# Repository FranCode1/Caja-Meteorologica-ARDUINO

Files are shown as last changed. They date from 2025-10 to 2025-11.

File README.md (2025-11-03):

# 🌱 Sistema de Monitoreo Ambiental con Arduino

Este proyecto utiliza un Arduino para monitorear variables ambientales como temperatura, humedad, luminosidad, calidad del aire y humedad del suelo. 
Los datos se registran en una tarjeta SD y pueden visualizarse por consola o pantalla LCD/OLED. 
El sistema está pensado para aplicaciones agrícolas, invernaderos o estaciones meteorológicas caseras.

## ✨ Características

- ⏰ RTC DS3231 — Reloj en tiempo real
- 🌡️ MLX90614(GY-906) — Sensor de temperatura infrarrojo
- 💨 MQ-135 — Sensor de calidad del aire
- 🌞 BH1750 — Sensor de luminosidad
- 💧 DS18B20 — Sensor de Temperatura del Agua
- 🌱 Capacitive Soil Moisture v2 — Humedad del suelo
- 💾 Módulo SD — Registro de datos
- ⚡ Comunicación I2C y monitoreo por Serial
- BMP280 —
- Pantalla LCD 20x4 con interfaz i2c —
- Joystick y botones —
- TCA9548A I2C Multiplexer —
- Transformador 5v 2A —
- Baterias 3AA x3 —
- Módulo de Conmutación Automática con Condensador — 

## 🗂️ Estructura del Proyecto

    ├── src/
    │   ├── main.ino
    │   ├── DS3231.h
    │   ├── GY906.h
    │   ├── MQ135.h
    │   ├── BH1750.h
    │   ├── CSMSV2.h
    │   └── SDCard.h
    ├── README.md
    └── /docs
        └── esquema_circuito.png

Cada sensor tiene su propio archivo `.h` modularizado, con funciones:
- `iniciarX()` → Inicializa el sensor
- `leerX()` → Lee los valores y los guarda en variables globales

## ⚙️ Requisitos

- Arduino UNO / Mega / Nano
- Librerías:
  - `Wire.h`
  - `RTClib.h`
  - `Adafruit_MLX90614.h`
  - `BH1750.h`
  - `SD.h`
- Fuente de 5V estable

## 🔌 Conexiones

| Componente | Tipo  | Pin Arduino |
|---|---|---|
| DS3231 (RTC) | I2C | SDA / SCL |
| GY-906 (Temp IR) | I2C | SDA / SCL |
| BH1750 (Luz) | I2C | SDA / SCL |
| MQ-135 (Gas) | Analógico | A1 |
| Sensor Tierra | Analógico | A0 |
| SD Card Module | SPI | CS, MOSI, MISO, SCK |

## Diagrama del circuito

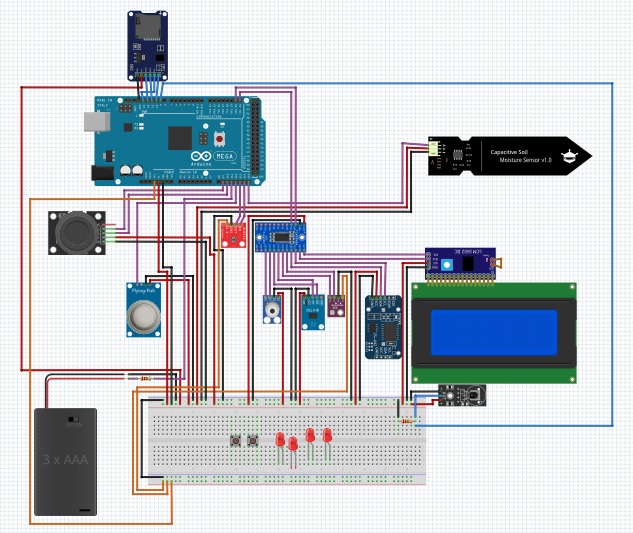
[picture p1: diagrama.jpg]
Diagrama del circuito


## 🧠 Funcionamiento del Código

1. Se inicializan todos los módulos (`iniciarX()`).
2. En el `loop()`, se leen los valores de cada sensor (`leerX()`).
3. Los datos se imprimen por Serial y se guardan en la tarjeta SD.
4. El reloj RTC agrega la marca de tiempo (`DD/MM/YYYY HH:MM:SS`).

## 📟 Ejemplo de salida Serial

    Fecha y Hora => Lun 17/10/2025 13:45:22
    BME280 => Temp: 24.6 °C, Humedad: 52%, Presión: 1012 hPa
    DS18B20 => Temp Agua: 23.1 °C
    CSMSV2 => Humedad Tierra: 71 %
    BH1750 => Luz: 580 lx
    ML8511 => UV: 1.2 uv
    MQ135 => Calidad Aire: 345 ppm CO2
    GY906 => Temp IR: 25.9 °C
-----------------------------

## 🔧 Calibración

- **MQ135:** Ejecutar `calibrarMQ135()` una sola vez en aire limpio.
- **Sensor de suelo:** Medir valores de `AIR_VALUE` (seco) y `WATER_VALUE` (mojado) y ajustar en `CSMSV2.h`.

## 🚀 Posibles Mejoras

- Enviar datos a un servidor IoT (ThingSpeak, Blynk, etc.)
- Agregar pantalla OLED para mostrar lecturas y reemplazar la botonera
- Sistema de riego automático según humedad del suelo

## 👨‍💻 Autor
**Franco Lugo** — Diseñador y desarrollador web / IoT enthusiast  

## 📜 Licencia
Este proyecto está bajo la licencia MIT — ver el archivo [LICENSE](LICENSE) para más detalles.

link de fritzing necesario: https://www.mediafire.com/file/of6y8ojzf2p2hle/Windows-fritzing-1.0.4.zip/file

link de las librerias del proyecto: 
https://www.mediafire.com/folder/pfqjpldbqcju3/Arduino

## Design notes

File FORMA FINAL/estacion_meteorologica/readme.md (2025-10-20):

# 🌱 Sistema de Monitoreo Ambiental con Arduino

Este proyecto utiliza un Arduino para monitorear variables ambientales como temperatura, humedad, luminosidad, calidad del aire y humedad del suelo. 
Los datos se registran en una tarjeta SD y pueden visualizarse por consola o pantalla LCD/OLED. 
El sistema está pensado para aplicaciones agrícolas, invernaderos o estaciones meteorológicas caseras.

## ✨ Características

- ⏰ RTC DS3231 — Reloj en tiempo real
- 🌡️ MLX90614 — Sensor de temperatura infrarrojo
- 💨 MQ-135 — Sensor de calidad del aire
- 💧 DHT22 / DHT11 — Sensor de temperatura y humedad
- 🌞 BH1750 — Sensor de luminosidad
- 🌱 Capacitive Soil Moisture v2 — Humedad del suelo
- 💾 Módulo SD — Registro de datos
- ⚡ Comunicación I2C y monitoreo por Serial

## 🗂️ Estructura del Proyecto

├── src/
│   ├── main.ino
│   ├── DS3231.h
│   ├── GY906.h
│   ├── MQ135.h
│   ├── BH1750.h
│   ├── CSMSV2.h
│   ├── DHT22.h
│   └── SDCard.h
├── README.md
└── /docs
    └── esquema_circuito.png

Cada sensor tiene su propio archivo `.h` modularizado, con funciones:
- `iniciarX()` → Inicializa el sensor
- `leerX()` → Lee los valores y los guarda en variables globales

## ⚙️ Requisitos

- Arduino UNO / Mega / Nano
- Librerías:
  - `Wire.h`
  - `RTClib.h`
  - `Adafruit_MLX90614.h`
  - `BH1750.h`
  - `DHT.h`
  - `SD.h`
- Fuente de 5V estable

## 🔌 Conexiones

| Componente | Tipo  | Pin Arduino |
|---|---|---|
| DS3231 (RTC) | I2C | SDA / SCL |
| GY-906 (Temp IR) | I2C | SDA / SCL |
| BH1750 (Luz) | I2C | SDA / SCL |
| MQ-135 (Gas) | Analógico | A1 |
| Sensor Tierra | Analógico | A0 |
| SD Card Module | SPI | CS, MOSI, MISO, SCK |

## Diagrama del circuito

Diagrama del circuito

## 🧠 Funcionamiento del Código

1. Se inicializan todos los módulos (`iniciarX()`).
2. En el `loop()`, se leen los valores de cada sensor (`leerX()`).
3. Los datos se imprimen por Serial y se guardan en la tarjeta SD.
4. El reloj RTC agrega la marca de tiempo (`DD/MM/YYYY HH:MM:SS`).

## 📟 Ejemplo de salida Serial

Fecha: 17/10/2025 - Hora: 13:45:22
BME280 => Temp: 24.6 °C, Humedad: 52%, Presión: 1012 hPa
DS18B20 => Temp Agua: 23.1 °C
CSMSV2 => Humedad Tierra: 71 %
BH1750 => Luz: 580 lx
ML8511 => UV: 1.2 uv
MQ135 => Calidad Aire: 345 ppm CO2
GY906 => Temp IR: 25.9 °C
-----------------------------

## 🔧 Calibración

- **MQ135:** Ejecutar `calibrarMQ135()` una sola vez en aire limpio.
- **Sensor de suelo:** Medir valores de `AIR_VALUE` (seco) y `WATER_VALUE` (mojado) y ajustar en `CSMSV2.h`.

## 🚀 Posibles Mejoras

- Enviar datos a un servidor IoT (ThingSpeak, Blynk, etc.)
- Agregar pantalla OLED para mostrar lecturas y reemplazar la botonera
- Sistema de riego automático según humedad del suelo

## 👨‍💻 Autor
**Franco Lugo** — Diseñador y desarrollador web / IoT enthusiast  

## 📜 Licencia
Este proyecto está bajo la licencia MIT — ver el archivo [LICENSE](LICENSE) para más detalles.

link de fritzing necesario: https://www.mediafire.com/file/of6y8ojzf2p2hle/Windows-fritzing-1.0.4.zip/file

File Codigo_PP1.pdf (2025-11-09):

Analista de Sistemas Año 1

# Prácticas Profesionalizantes 1 Proyecto: Estación Meteorológica

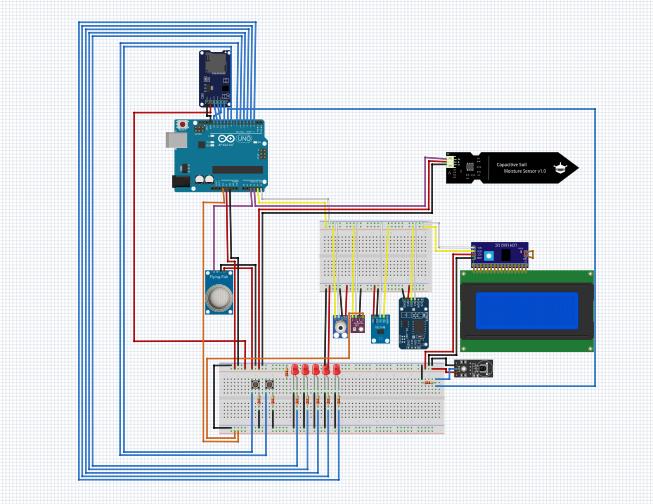
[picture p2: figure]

Integrantes: Facundo Neiel Molina, Franco Lugo, Ivan Ruiz, Mauro Diaz Año: 2025 estacion_meteorologica.ino

// ===================================================== // ESTACIÓN METEOROLÓGICA - PROGRAMA PRINCIPAL
// ===================================================== // Control central de sensores, pantalla y almacenamiento.
// Lectura modular, navegación y registro optimizado.
// =====================================================

// ===================================================== // LIBRERÍAS PRINCIPALES
// =====================================================
#include <Wire.h> | // Comunicación I2C

#include "lcd.h" | // Pantalla LCD

#include "navegacion.h" // Botones y control de pantallas

// ===================================================== // MÓDULOS ACTIVOS
// ===================================================== #include "bmp280.h" // Temp, presión y altitud
#include "ds18b20.h" // Temp del agua

#include "csmsv2.h" | // Humedad del suelo

#include "bh1750.h" | // Luz ambiental

#include "mq135.h" | // Gases / CO₂

#include "gy906.h" | // Temp infrarroja

#include "ds3231.h" | // Reloj en tiempo real

#include "microsd.h" // Registro en tarjeta SD

#include "leds_guia.h" // Indicadores LED por pantalla

// ===================================================== // CONFIGURACIÓN INICIAL
// ===================================================== void setup() {
Serial.begin(9600);
Wire.begin();
iniciarSD(); | // Inicia microSD
iniciarPantalla(); | // LCD
iniciarLedsPantalla(); // LEDs cambiarLedPantalla(1); // LED inicial iniciarRTC(); // Reloj

iniciarBMP(); | // BMP280
iniciarBH1750(); | // BH1750
iniciarGY906(); | // Si está conectado
iniciarDS18B20(); | // DS18B20
iniciarCSMSV2(); | // Humedad suelo
iniciarMQ135(); | // MQ135
iniciarNavegacion(); | // Botones
calibrarMQ135(); | // Calibración gases
mostrarPantalla(1); | // Pantalla inicial
}

// ===================================================== // BUCLE PRINCIPAL
// ===================================================== void loop() {
leerNavegacion(); | // Botones / cambio de pantallas
leerRTC(); | // Hora y fecha
leerBMP(); | // Presión y altitud
leerBH1750(); | // Luz
leerGY906(); | // Infrarrojo
leerDS18B20(); | // Temp agua
leerCSMSV2(); | // Humedad tierra
leerMQ135(); | // CO₂
escribirSD("registro.txt"); // Guarda datos cambiarLedPantalla(pantallaActual); // LED activo
delay(1000); | // Actualización cada segundo
}

lcd.h

#ifndef _LCD_H

#define _LCD_H

// ===================================================== // LIBRERÍAS
// ===================================================== #include <Arduino.h>
#include <LiquidCrystal_I2C.h>

// =====================================================

// VARIABLES EXTERNAS DE SENSORES
// ===================================================== extern float temp_bmp280, presion_bmp280, altitud_bmp280; extern float temp_ds18b20;
extern uint8_t humedad_tierra;
extern float ratio;
extern String calidad, tendencia;
extern float lux;
extern float TEMP_OBJETO_GY906;
extern String FECHA, HORARIO, DIA_SEMANA;

// ===================================================== // LCD CONFIGURACIÓN
// ===================================================== LiquidCrystal_I2C lcd(0x27, 20, 4); // Dir I2C y tamaño (20x4)

// ===================================================== // FUNCIONES DE CONTROL LCD
// =====================================================

// Pantalla de bienvenida
inline void pantallaInicio() {
lcd.clear();
lcd.setCursor(4, 0); lcd.print("!Bienvenidos"); lcd.setCursor(8, 1); lcd.print("a la"); lcd.setCursor(6, 2); lcd.print("Estacion"); lcd.setCursor(4, 3); lcd.print("Meteorologica!");
delay(3000);
}

// ===================================================== // PANTALLAS DE INFORMACIÓN
// =====================================================

inline void pantallaBMP280() {
lcd.clear();
lcd.setCursor(0, 0); lcd.print("<=====BMP280=====>");
lcd.setCursor(0, 1); lcd.print("Temp: "); lcd.print(temp_bmp280, 1); lcd.print(" C"); lcd.setCursor(0, 2); lcd.print("Presion: "); lcd.print(presion_bmp280, 1); lcd.print(" hPa"); lcd.setCursor(0, 3); lcd.print("Altitud: "); lcd.print(altitud_bmp280, 1); lcd.print(" m");
}

inline void pantallaDS18_CSMS() {

lcd.clear();
lcd.setCursor(0, 0); lcd.print("<=====DS18B20====>");
lcd.setCursor(0, 1); lcd.print("Temp Agua: "); lcd.print(temp_ds18b20, 1); lcd.print(" C"); lcd.setCursor(0, 2); lcd.print("<=====CSMSV2=====>");
lcd.setCursor(0, 3); lcd.print("Humedad: "); lcd.print(humedad_tierra); lcd.print(" %"); }

inline void pantallaMQ135() {
lcd.clear();
lcd.setCursor(0, 0); lcd.print("<======MQ135======>"); lcd.setCursor(0, 1); lcd.print("CO2: "); lcd.print(ratio, 1); lcd.print("%"); lcd.setCursor(0, 2); lcd.print("Estado: "); lcd.print(calidad); lcd.setCursor(0, 3); lcd.print("Tendencia: "); lcd.print(tendencia);
}

inline void pantallaBH_GY() {
lcd.clear();
lcd.setCursor(0, 0); lcd.print("<=====BH1750=====>");
lcd.setCursor(0, 1); lcd.print("Lux: "); lcd.print(lux, 1);
lcd.setCursor(0, 2); lcd.print("<=====GY906======>");
lcd.setCursor(0, 3); lcd.print("Temp IR: "); lcd.print(TEMP_OBJETO_GY906, 1); lcd.print(" C"); }

inline void pantallaRTC() {
lcd.clear();
lcd.setCursor(0, 0); lcd.print("<=======FECHA======>"); lcd.setCursor(0, 1); lcd.print("Dia: "); lcd.print(DIA_SEMANA); lcd.print(" "); lcd.print(FECHA);
lcd.setCursor(0, 2); lcd.print("<======HORARIO=====>"); lcd.setCursor(0, 3); lcd.print("Hora: "); lcd.print(HORARIO);
}

// ===================================================== // INICIALIZACIÓN
// ===================================================== inline void iniciarPantalla() {
lcd.begin(20, 4);
lcd.backlight();
lcd.clear();
pantallaInicio();
}

// =====================================================

// CAMBIO DE PANTALLAS
// ===================================================== uint8_t pantallaActual = 0;

void mostrarPantalla(uint8_t id) {
pantallaActual = id;
switch (id) {
case 0: pantallaBMP280(); break; case 1: pantallaDS18_CSMS(); break; case 2: pantallaMQ135(); break; case 3: pantallaBH_GY(); break; case 4: pantallaRTC(); break;
}
}

#endif

Navegación.h

#ifndef _NAVEGACION_H_

#define _NAVEGACION_H_

#include <Arduino.h>

#include "lcd.h" // Para usar mostrarPantalla()

// =================================================== // CONFIGURACIÓN DE PINES DE LOS BOTONES
// =================================================== // Usa resistencias pull-up internas.
// Los botones se conectan entre el pin y GND.
#define BTN_IZQ 4

#define BTN_DER 3

// =================================================== // VARIABLES DE CONTROL (Antirrebote)
// =================================================== unsigned long ultimoMovimiento = 0;

const unsigned long debounceDelay = 250; // milisegundos entre movimientos

// ===================================================
// VARIABLES DE CONTROL DE PANTALLA
// ===================================================
extern uint8_t pantallaActual; // declarada en lcd.h
const uint8_t totalPantallas = 5; // cantidad total de pantallas (ajustá si cambian)

// ===================================================
// INICIALIZACIÓN DE BOTONES
// ===================================================
inline void iniciarNavegacion() {
pinMode(BTN_IZQ, INPUT_PULLUP);
pinMode(BTN_DER, INPUT_PULLUP);
// Serial.println(F("Navegación por botones iniciada correctamente.")); }

// ===================================================
// LECTURA DE BOTONES Y NAVEGACIÓN
// =================================================== inline void leerNavegacion() {
unsigned long ahora = millis();
if (ahora - ultimoMovimiento < debounceDelay)
return;

// Botón IZQUIERDA
if (!digitalRead(BTN_IZQ)) {
if (pantallaActual == 0) pantallaActual = totalPantallas - 1; else pantallaActual--;
mostrarPantalla(pantallaActual);
ultimoMovimiento = ahora;
return;
}

// Botón DERECHA
if (!digitalRead(BTN_DER)) {
pantallaActual = (pantallaActual + 1) % totalPantallas; mostrarPantalla(pantallaActual);
ultimoMovimiento = ahora;
return;
}
}

#endif

Leds_guia.h

#ifndef _LCD_GUIA_H

#define _LCD_GUIA_H

#include "lcd.h" // Tu archivo donde inicializás LiquidCrystal

// ===================================================== // CONTROL DE LEDS SEGÚN LA "PANTALLA" ACTUAL
// ===================================================== // Cada pantalla del LCD tendrá un LED indicador asociado.
// Por ejemplo, si mostrás distintas lecturas de sensores,
// podés prender el LED correspondiente a la pantalla activa.

#define LED_PANTALLA1 6

#define LED_PANTALLA2 5

#define LED_PANTALLA3 4

#define LED_PANTALLA4 3

#define LED_PANTALLA5 2

// Variables globales
static unsigned long ultimoParpadeo = 0;
static bool estadoLED = false;
extern uint8_t pantallaActual; // declarada en lcd.h

// -------------------------------------------------------------
// Inicializa los pines de los LEDs como salidas
// -------------------------------------------------------------
void iniciarLedsPantalla() {
const uint8_t leds[5] = {LED_PANTALLA1, LED_PANTALLA2, LED_PANTALLA3, LED_PANTALLA4, LED_PANTALLA5};
for (uint8_t i = 0; i < 5; i++) {
pinMode(leds[i], OUTPUT);
digitalWrite(leds[i], LOW);
}
}

// -------------------------------------------------------------
// Cambia la pantalla activa y enciende su LED correspondiente // -------------------------------------------------------------void cambiarLedPantalla(uint8_t nuevaPantalla) { if (nuevaPantalla < 1 || nuevaPantalla > 5) return; pantallaActual = nuevaPantalla;

// Apaga todos los LEDs
digitalWrite(LED_PANTALLA1, LOW); digitalWrite(LED_PANTALLA2, LOW); digitalWrite(LED_PANTALLA3, LOW); digitalWrite(LED_PANTALLA4, LOW); digitalWrite(LED_PANTALLA5, LOW);

// Enciende solo el LED de la pantalla activa
switch (pantallaActual) {
case 1: digitalWrite(LED_PANTALLA1, HIGH); break; case 2: digitalWrite(LED_PANTALLA2, HIGH); break; case 3: digitalWrite(LED_PANTALLA3, HIGH); break; case 4: digitalWrite(LED_PANTALLA4, HIGH); break; case 5: digitalWrite(LED_PANTALLA5, HIGH); break; }
}

#endif

MicroSD.h

#ifndef _MICROSD_H

#define _MICROSD_H

// ===================================================================== // MÓDULO MICROSD - LECTURA Y ESCRITURA DE DATOS
// ===================================================================== // Este módulo maneja la escritura de los datos de los sensores en una
// tarjeta microSD y la lectura opcional de registros. También utiliza

// la memoria EEPROM para conservar el número de registro más reciente.
// =====================================================================

// ---------------------------------------------------------------------
// LIBRERÍAS NECESARIAS
// ---------------------------------------------------------------------
#include <Arduino.h>

#include <SPI.h> | // Comunicación SPI (Serial Peripheral Interface)

#include <SD.h> | // Librería oficial de Arduino para manejo de tarjetas SD

#include <EEPROM.h> // Permite leer y escribir en la memoria EEPROM interna

// ---------------------------------------------------------------------
// VARIABLES EXTERNAS DE SENSORES
// ---------------------------------------------------------------------
// Se traen únicamente las variables necesarias desde los módulos de
// sensores, para reducir el peso total del programa. Cada variable es
// declarada como 'extern' porque su definición real está en otro archivo.
extern float temp_bmp280, presion_bmp280, altitud_bmp280; // BMP280 → temperatura, presión y altitud
extern float temp_ds18b20; | // DS18B20 → temperatura del agua
extern uint8_t humedad_tierra; | // CSMSV2 → humedad del suelo
extern float ratio; | // MQ-135 → relación de CO₂
extern String calidad, tendencia; | // MQ-135 → estado y tendencia del aire
extern float lux; | // BH1750 → luz ambiental (lux)
extern float TEMP_OBJETO_GY906; | // GY-906 → temperatura infrarroja
extern String FECHA, HORARIO; | // DS3231 → fecha y hora actual

// ---------------------------------------------------------------------
// CONFIGURACIÓN DEL MÓDULO MICROSD
// ---------------------------------------------------------------------

// Pin Chip Select (SS) del módulo microSD.
// Nota: este valor puede variar según la placa o el módulo utilizado.
// Ejemplo común: 10 para Arduino UNO, 5 para ESP32, etc.
#define SD_CS_PIN 10

// Contador de registros (se conserva el valor entre reinicios usando EEPROM) int registroID = 0;

// Objeto global para manejar archivos en la tarjeta SD
File archivo;

// ---------------------------------------------------------------------

// FUNCIÓN: iniciarSD()
// ---------------------------------------------------------------------
// Inicializa la tarjeta microSD y carga el último ID guardado desde EEPROM. // Devuelve:
// true → si la inicialización fue exitosa
// false → si falló la inicialización
// ---------------------------------------------------------------------
bool iniciarSD() {
// Serial.println(F("Inicializando tarjeta microSD...")); // DEBUG opcional

// Intentar inicializar la tarjeta (descomentá si necesitás verificar)
/*
if (!SD.begin(SD_CS_PIN)) {
Serial.println(F("Error: no se pudo inicializar la tarjeta SD")); return false;
}
*/

// Leer último ID guardado desde la EEPROM EEPROM.get(0, registroID);

// Si el valor leído no es válido, comenzar desde 1
if (registroID < 1)
registroID = 1;

// Serial.println(F("Tarjeta microSD lista para usar")); // DEBUG opcional return true;
}

// ---------------------------------------------------------------------
// FUNCIÓN: escribirSD(const char *nombreArchivo)
// ---------------------------------------------------------------------
// Escribe en la tarjeta SD los valores actuales de los sensores.
// Crea el archivo si no existe, o agrega información al final si ya existe. //
// Parámetros:
// nombreArchivo → nombre del archivo donde guardar (ej: "datos.txt") //
// Devuelve:
// true → si la escritura fue exitosa
// false → si hubo error al abrir o escribir el archivo // ---------------------------------------------------------------------bool escribirSD(const char *nombreArchivo) {

// Abrir archivo en modo escritura (crea si no existe)
archivo = SD.open(nombreArchivo, FILE_WRITE);

if (archivo) {
// ===================================================== // BLOQUE DE ESCRITURA DE DATOS
// =====================================================

// --- ID del registro ---
archivo.print("Registro ID: ");
archivo.println(String(registroID++)); // Incrementa para el siguiente registro

// --- Fecha y hora del RTC ---
archivo.print("Hora y Fecha: ");
archivo.println(leerRTC()); // Función proveniente del módulo DS3231

// --- Sensor BMP280 ---
archivo.print("BMP280 → ");
archivo.print("Temp: "); archivo.print(temp_bmp280); archivo.print(" °C "); archivo.print("Pres: "); archivo.print(presion_bmp280); archivo.print(" hPa "); archivo.print("Alti: "); archivo.print(altitud_bmp280); archivo.println(" m");

// --- Sensor DS18B20 ---
archivo.print("DS18B20 → ");
archivo.print("Temp. Agua: "); archivo.print(temp_ds18b20); archivo.println(" °C");

// --- Sensor CSMSV2 ---
archivo.print("CSMSV2 → ");
archivo.print("Humedad Tierra: "); archivo.print(humedad_tierra); archivo.println(" %");

// --- Sensor BH1750 ---
archivo.print("BH1750 → ");
archivo.print("Luz: "); archivo.print(lux); archivo.println(" lx");

// --- Sensor MQ-135 ---
archivo.print("MQ-135 → ");
archivo.print("CO₂: "); archivo.print(ratio); archivo.print("% | ");
archivo.print("Estado: "); archivo.print(calidad);
archivo.print(" | Tendencia: "); archivo.println(tendencia);

// --- Sensor GY-906 ---
archivo.print("GY-906 → ");

archivo.print("Temp. Infrarroja: "); archivo.print(TEMP_OBJETO_GY906); archivo.println(" °C");

// =====================================================
// FINALIZACIÓN
// ===================================================== archivo.close(); // Siempre cerrar tras escribir
EEPROM.put(0, registroID); // Guardar nuevo ID en EEPROM

// Serial.print(F("Datos escritos en ")); Serial.println(nombreArchivo); // DEBUG return true;
}

// Si el archivo no se pudo abrir:
// Serial.print(F("Error al abrir ")); Serial.println(nombreArchivo); // DEBUG return false;
}

// ---------------------------------------------------------------------
// FUNCIÓN OPCIONAL: leerSD(const char *nombreArchivo)
// ---------------------------------------------------------------------
// Lee el contenido completo de un archivo de la tarjeta SD y lo muestra // por el monitor serie. Ideal para depuración o pruebas.
// ---------------------------------------------------------------------
/*
void leerSD(const char *nombreArchivo) {
archivo = SD.open(nombreArchivo);

if (archivo) {
Serial.print(F("Contenido de ")); Serial.println(nombreArchivo); Serial.println(F("------------------------"));

while (archivo.available()) {
Serial.write(archivo.read());
}

archivo.close();
Serial.println(F("\n------------------------"));
Serial.println(F("Lectura finalizada"));
} else {
Serial.print(F("Error al abrir ")); Serial.println(nombreArchivo); }
}

*/

#endif

Ds3231.h

#ifndef _DS3231_H

#define _DS3231_H

#include <Arduino.h>

#include <RTClib.h>

// ===================== OBJETO DEL RTC ===================== RTC_DS3231 rtc;
DateTime fecha;

// ===================== VARIABLES GLOBALES ===================== int DIA, MES, ANIO, HORA, MINUTO, SEGUNDO;
String DIA_SEMANA, FECHA, HORARIO;

// ===================== INICIO =====================
inline void iniciarRTC() {
// Wire.begin(); // Si no se inicializa en otro módulo

// Inicializa y ajusta automáticamente con la hora de compilación rtc.begin();
rtc.adjust(DateTime(__DATE__, __TIME__));
}

// ===================== NOMBRE DEL DÍA ===================== inline String obtenerNombreDia(uint8_t diaSemana) {
switch (diaSemana) {
case 1: return "Dom";
case 2: return "Lun";
case 3: return "Mar";
case 4: return "Mie";
case 5: return "Jue";

case 6: return "Vie";
case 7: return "Sab";
default: return "???";
}
}

// ===================== LECTURA ===================== inline String leerRTC() {
fecha = rtc.now();

DIA = fecha.day();
MES = fecha.month();
ANIO = fecha.year();
HORA = fecha.hour();
MINUTO = fecha.minute();
SEGUNDO = fecha.second();
DIA_SEMANA = obtenerNombreDia(fecha.dayOfTheWeek() + 1);

char buffer[35];
sprintf(buffer, "%s %02d/%02d/%04d %02d:%02d:%02d", DIA_SEMANA.c_str(), DIA, MES, ANIO, HORA, MINUTO, SEGUNDO);

return String(buffer);
}

#endif

Bh1750.h

#ifndef _BH1750_H

#define _BH1750_H

#include <Arduino.h>

#include <BH1750.h>

// ===================== SENSOR ===================== BH1750 sensorBH1750; // Comunicación I2C (SDA, SCL)

// ===================== VARIABLES ===================== float lux = 0.0F; // Nivel de luz ambiental en lux

// ===================== INICIO ===================== inline void iniciarBH1750() {
// Wire.begin(); // Si no se inicializa en otro módulo sensorBH1750.begin();
}

// ===================== LECTURA ===================== inline void leerBH1750() {
lux = sensorBH1750.readLightLevel();
}

#endif

Bmp280.h

#ifndef _BMP280_H

#define _BMP280_H

#include <Arduino.h>

#include <Adafruit_BMP280.h> // Librería del sensor BMP280

// ===================== SENSOR ===================== Adafruit_BMP280 bmp; // Comunicación I2C (SDA, SCL)

// ===================== VARIABLES ===================== static float temp_bmp280 = 0.0F;
static float presion_bmp280 = 0.0F;
static float altitud_bmp280 = 0.0F;
static float p0_bmp = 0.0F; // Presión base (nivel del mar)

// ===================== UMBRALES ===================== #define TEMP_MAX 35.0F
#define PRESION_MIN 950.0F

#define PRESION_MAX 1050.0F

#define ALTITUD_MAX 300.0F

// ===================== INICIO ===================== inline void iniciarBMP() {
// Dirección I2C 0x76 (usa 0x77 según módulo)
// if (!bmp.begin(0x76)) while (1); // Para debug
p0_bmp = bmp.readPressure() / 100.0F;
}

// ===================== LECTURA ===================== inline void leerBMP() {
temp_bmp280 = bmp.readTemperature();
presion_bmp280 = bmp.readPressure() / 100.0F; // Pa → hPa altitud_bmp280 = 44330 * (1.0 - pow(presion_bmp280 / 1013.25, 0.1903)); }

#endif

Csmsv2.h

#ifndef _CSMSV2_H

#define _CSMSV2_H

#include <Arduino.h>

// ===================== CONFIGURACIÓN ===================== #define PIN_SENSOR_TIERRA A0 // Pin analógico del sensor
#define HUMEDAD_MIN_SEGURA 25 // Mínimo aceptable (%)

#define HUMEDAD_MAX_SEGURA 90 // Máximo aceptable (%)

const int AIR_VALUE = 588; // Valor en aire seco
const int WATER_VALUE = 308; // Valor en agua

// ===================== VARIABLE ===================== static uint8_t humedad_tierra = 0; // % de humedad actual

// ===================== INICIO ===================== inline void iniciarCSMSV2() {
pinMode(PIN_SENSOR_TIERRA, INPUT);
}

// ===================== LECTURA ===================== inline void leerCSMSV2() {
int lectura = analogRead(PIN_SENSOR_TIERRA); // Leer valor ADC humedad_tierra = map(lectura, AIR_VALUE, WATER_VALUE, 0, 100); humedad_tierra = constrain(humedad_tierra, 0, 100);
}

#endif

Ds18b20.h

#ifndef _DS18B20_H

#define _DS18B20_H

#include <Arduino.h>

#include <OneWire.h>

#include <DallasTemperature.h>

// ===================== CONFIGURACIÓN ===================== #define DS18B20_PIN 2 // Pin de datos OneWire
#define TEMP_MAX_DS18B20 37.0 // Temperatura máxima segura #define TEMP_MIN_DS18B20 -10.0 // Temperatura mínima opcional

// ===================== OBJETOS ===================== static OneWire oneWire(DS18B20_PIN); // Comunicación OneWire static DallasTemperature sensors(&oneWire); // Controlador del sensor

// ===================== VARIABLE ===================== static float temp_ds18b20 = 0.0; // Temperatura actual (°C)

// ===================== INICIO =====================
inline void iniciarDS18B20() {
sensors.begin(); // Inicia comunicación
}

// ===================== LECTURA ===================== inline void leerDS18B20() {
sensors.requestTemperatures(); // Solicita medición temp_ds18b20 = sensors.getTempCByIndex(0); // Lee temperatura }

#endif

Gy906.h

#ifndef _GY906_H

#define _GY906_H

#include <Adafruit_MLX90614.h>

// ===================================================================== // OBJETO DEL SENSOR
// ===================================================================== static Adafruit_MLX90614 gy906;

// ===================================================================== // VARIABLES DE MEDICIÓN
// ===================================================================== // Notas:
// - Se usa 'static' para limitar el alcance al archivo (evita duplicaciones)
// - Se usa 'float' porque la librería devuelve ese tipo
static float TEMP_AMBIENTE_GY906 = 0;
static float TEMP_OBJETO_GY906 = 0;

// ===================================================================== // FUNCIONES
// =====================================================================

// Inicializa el sensor (llamar una sola vez)
inline void iniciarGY906() {
if (!gy906.begin()) {
Serial.println(F("Error GY-906")); while (true); // Error crítico
}
Serial.println(F("GY-906 OK"));
}

// Lee las temperaturas ambiente y de objeto
inline void leerGY906() {
TEMP_AMBIENTE_GY906 = gy906.readAmbientTempC(); TEMP_OBJETO_GY906 = gy906.readObjectTempC();
}

#endif

Mq135.h

#ifndef _MQ135_H

#define _MQ135_H

#include <Arduino.h>

// ===================== CONFIGURACIÓN ===================== constexpr uint8_t MQ135_PIN = A2; // Pin analógico del sensor constexpr float RL = 1.0; // Resistencia de carga (kΩ)
constexpr float CLEAN_AIR_RATIO = 9.8; // RS/RO en aire limpio

// ===================== VARIABLES =====================
float RO = 10.0; | // Resistencia base (aire limpio)
float RS = 0.0; | // Resistencia actual del sensor
float ratio = 0.0; // Relación RS/RO
float ratio_anterior = 0;
String calidad = "Desconocida";
String tendencia = "Estable";

// ===================== CALIBRACIÓN ===================== inline void calibrarMQ135() {
float RS_sum = 0.0;

// Promedia 50 lecturas en aire limpio
for (uint8_t i = 0; i < 50; i++) {
int adc = analogRead(MQ135_PIN); if (adc == 0) adc = 1;
float rs = RL * (1023.0 / adc - 1.0); RS_sum += rs;
delay(100);
}

RS = RS_sum / 100.0;
RO = RS / CLEAN_AIR_RATIO;
}

// ===================== LECTURA ===================== inline float leerMQ135() {
int adc = analogRead(MQ135_PIN);

if (adc == 0) adc = 1;

RS = RL * (1023.0 / adc - 1.0);
ratio = RS / RO;

// Clasificación del aire
if (ratio > 3.0) calidad = F("Excelente"); else if (ratio > 2.0) calidad = F("Buena"); else if (ratio > 1.5) calidad = F("Regular"); else if (ratio > 1.0) calidad = F("Mala");
else | calidad = F("Crítica");

// Tendencia
if (ratio > ratio_anterior + 0.1) tendencia = F("Empeorando ↑"); else if (ratio < ratio_anterior - 0.1) tendencia = F("Mejorando ↓");
else | tendencia = F("Estable →");

ratio_anterior = ratio;
return ratio;
}

// ===================== INICIO ===================== inline void iniciarMQ135() {
pinMode(MQ135_PIN, INPUT);
calibrarMQ135();
}

#endif

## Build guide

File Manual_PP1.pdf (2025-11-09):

Analista deSistemas Año 1

# Prácticas Profesionalizantes 1 Proyecto: Estación Meteorológica

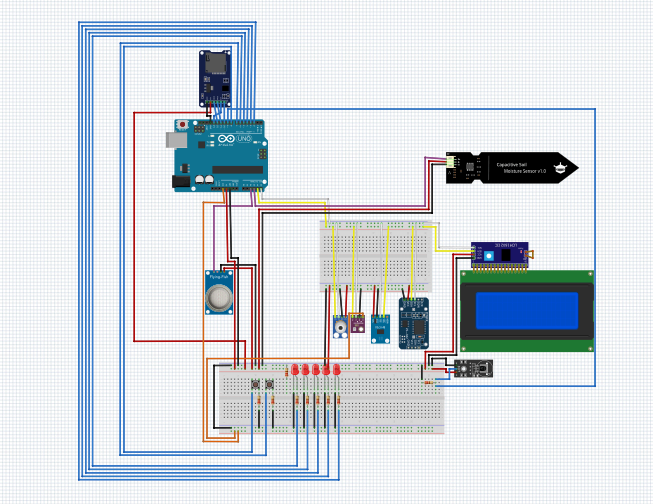
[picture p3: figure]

Integrantes: Facundo Neiel Molina, Franco Lugo, Ivan Ruiz, Mauro Diaz Año: 2025

## Introducción:

Este proyecto utiliza un Arduino para monitorear variables ambientales como temperatura, humedad, luminosidad, calidad del aire y humedad del suelo. Los datos se registran en una tarjeta SD y pueden visualizarse por consola o pantalla LCD/OLED. El sistema está pensado para aplicaciones agrícolas, invernaderos o estaciones meteorológicas caseras.

### Características y Conexiones:

Arduino Uno:

El Arduino Uno es una placa de microcontrolador de código abierto basada principalmente en el ATmega328P, diseñada para facilitar el desarrollo de proyectos electrónicos interactivos.

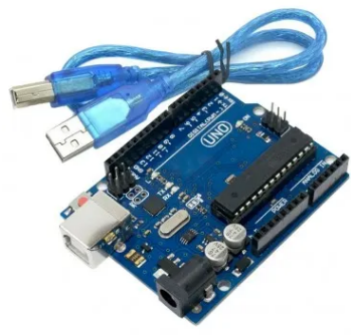
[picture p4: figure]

Módulo SD — Registro de datos:

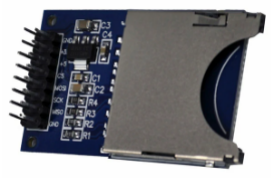
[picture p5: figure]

El módulo de tarjeta Micro SD para Arduino es un dispositivo que permite la lectura y escritura de tarjetas Micro SD y Micro SDHC, ofreciendo una solución práctica para añadir almacenamiento externo a proyectos basados en Arduino.

SPI | 5v

RTC DS3231 — Reloj en tiempo real:

Este dispositivo mantiene con precisión la hora, minutos, segundos, día de la semana, fecha, mes y año, ajustando automáticamente la fecha al final de los meses con menos de 31 días, incluyendo las correcciones para años bisiestos hasta el año 2100.

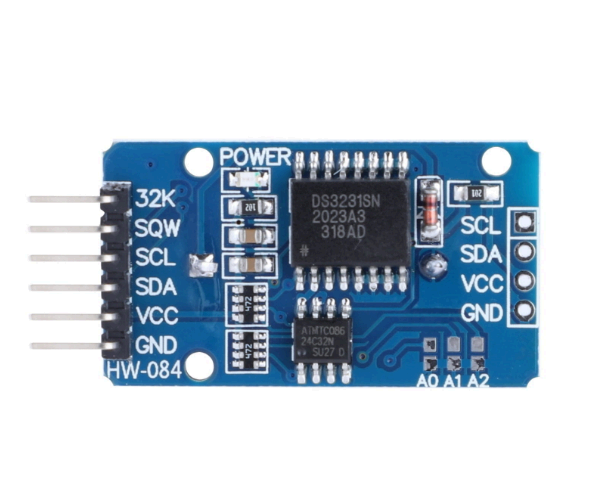
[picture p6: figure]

SDA / SCL | 5v

Capacitive Soil Moisture v2 — Humedad del suelo:

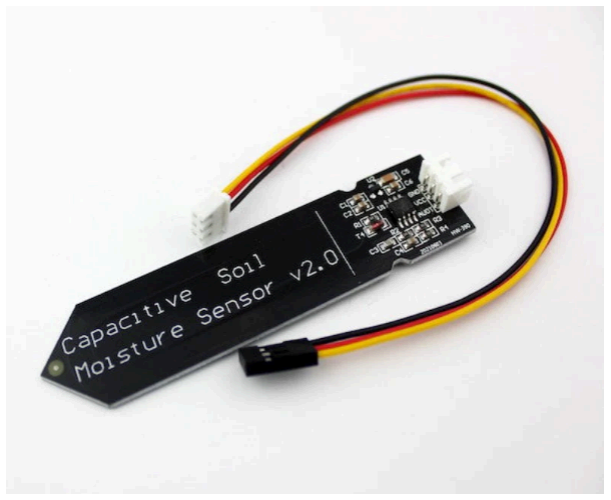
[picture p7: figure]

El Sensor de humedad de suelo capacitivo v1.2 permite medir la humedad en el suelo utilizando el principio de capacitancia entre electrodos en lugar de resistencia, lo que aumenta considerablemente la vida útil del sensor.

A3 | 5v

MQ-135 — Sensor de calidad del aire:

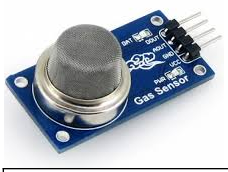
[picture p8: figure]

El sensor MQ-135 es un dispositivo electrónico diseñado para detectar la presencia de diversos gases nocivos en el aire, siendo ampliamente utilizado en sistemas de monitoreo de calidad del aire.

A2 | 5v

BH1750 — Sensor de luminosidad:

El sensor BH1750 es un dispositivo digital diseñado para medir la intensidad de la luz ambiental, proporcionando lecturas directas en unidades de lux (lx), que es la medida estándar de iluminancia o nivel de iluminación.

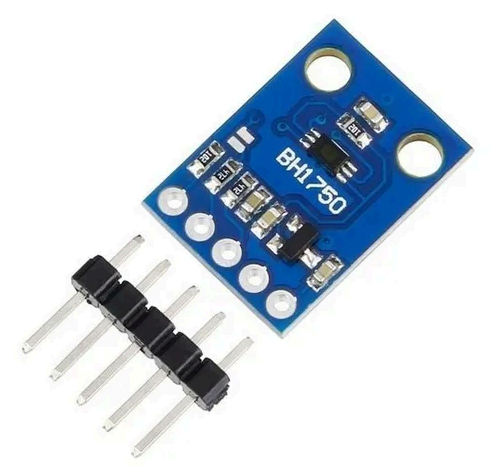
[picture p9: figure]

SDA / SCL | 3.3v

DS18B20 — Sensor de Temperatura del Agua:

El sensor de temperatura digital DS18B20 es un dispositivo altamente preciso y fácil de usar, diseñado para medir temperaturas en un rango de –55 °C a +125 °C, con una precisión típica de ±0.5 °C en el rango de –10 °C a +85 °C.

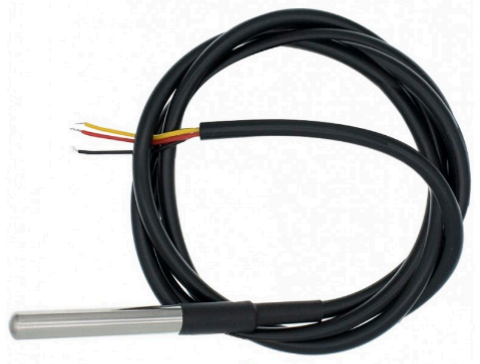
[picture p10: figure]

D9 | 5v

MLX90614(GY-906) — Sensor de temperatura infrarrojo:

El sensor de temperatura infrarrojo MLX90614 es un chip de silicio con una fina membrana micro mecanizada diseñada para detectar la radiación infrarroja emitida por objetos a distancia, permitiendo medir su temperatura sin contacto físico.

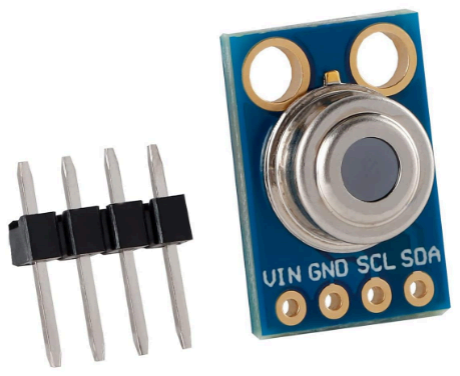
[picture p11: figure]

SDA / SCL | 3.3v - 5v

Pantalla LCD 20x4 con interfaz i2c — Interfaz:

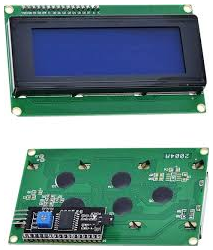
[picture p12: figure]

Es un componente de visualización alfanumérica que simplifica la conexión y programación en proyectos con microcontroladores. A diferencia de las pantallas LCD estándar que requieren muchos pines de conexión, este modelo integra un módulo I2C (Inter-Integrated Circuit), lo que reduce la cantidad de cables a solo cuatro.

Transformador 5v 2A — Alimentación:

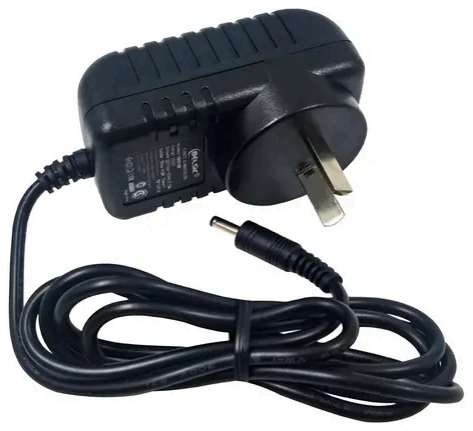
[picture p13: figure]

Convierte la corriente eléctrica del tomacorriente de pared a 5 voltios de corriente continua, con una capacidad de entregar hasta 2 amperios. Es comúnmente utilizado para alimentar o cargar dispositivos como celulares, tablets, routers, cámaras y otros aparatos
electrónicos.
SDA / SCL | 5v

Leds:

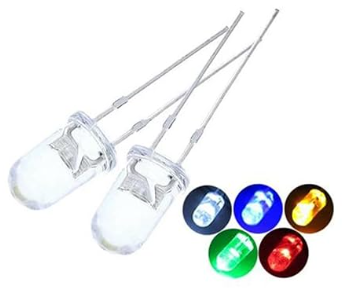
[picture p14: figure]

Un diodo emisor de luz (LED) es un dispositivo semiconductor que emite luz cuando se aplica una corriente eléctrica a través de él.

D6, D5, D4, D3, D2 | 5v

Leds:

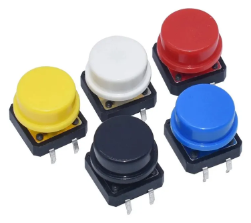
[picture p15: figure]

| Conectar y programar pulsadores con Arduino es esencial para proyectos interactivos. El uso incorrecto puede provocar lecturas inestables debido al "estado de alta impedancia", que se soluciona con resistencias pull-up o pull-down, ya sean externas o internas.
| Diagrama Esquemático:

Requisitos:

- Arduino UNO / Mega / Nano
- Librerías Externas:
- Arduino.h
- Adafruit_BMP280.h
- Adafruit_Sensor.h
- LiquidCrystal_I2C.h
- LiquidMenu.h
- OneWire.h
- DallasTemperature.h
- Wire.h
- RTClib.h

- Adafruit_MLX90614.h
- EEPROM.h
- SPI.h
- SD.h
- Librerías Internas:
- lcd.h
- mq135.h
- navegacion.h
- leds_guia.h
- microsd.h
- gy906.h
- ds3231.h
- ds18b20.h
- csmsv2.h
- bmp280.h
- bh1750.h
- Fuente de 5V estable

Guía de Uso:

TOUR POR LA ESTACION METEOROLOGICA:

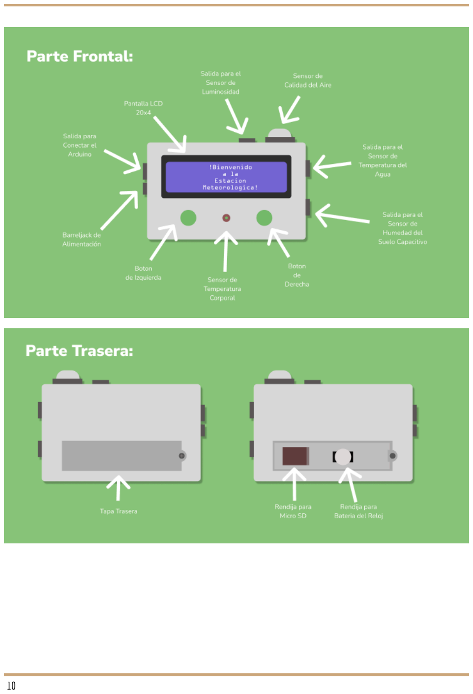
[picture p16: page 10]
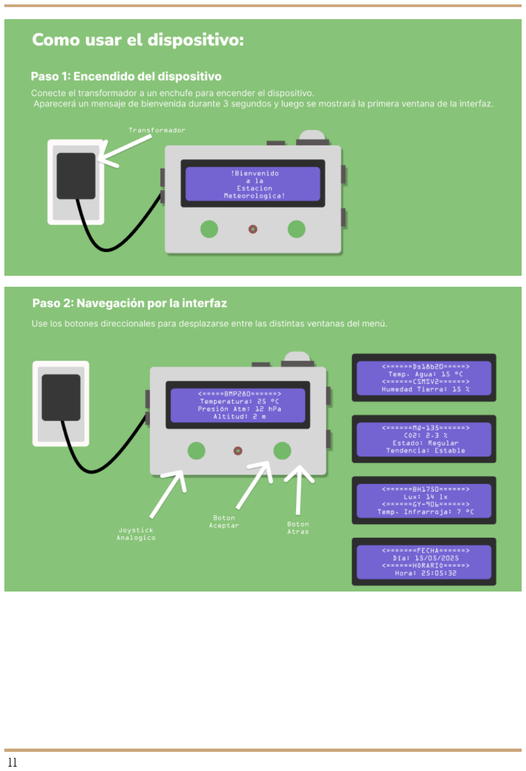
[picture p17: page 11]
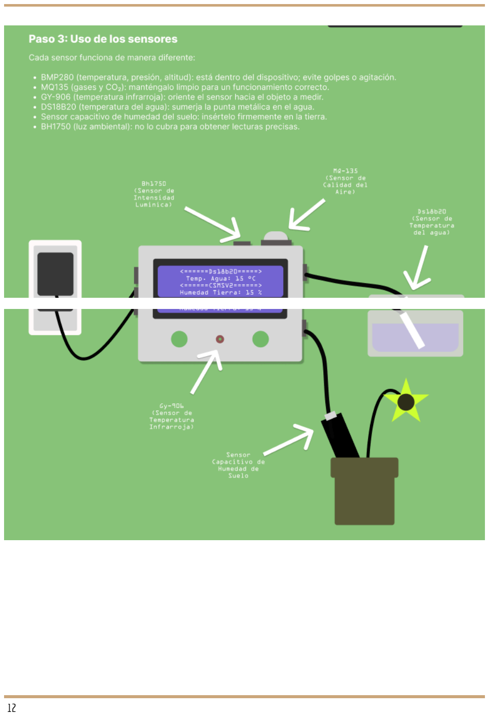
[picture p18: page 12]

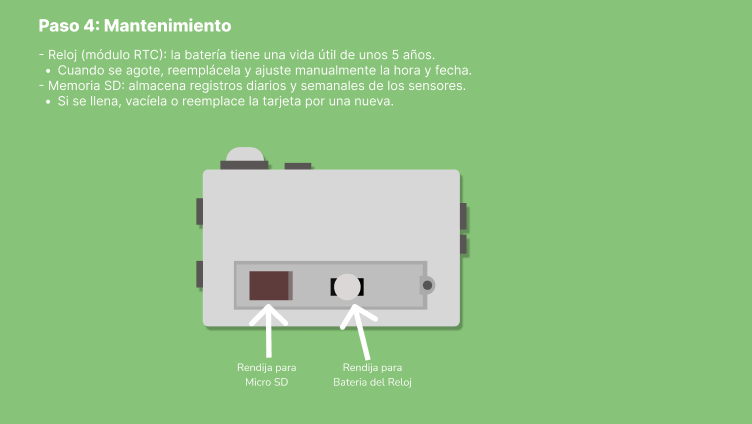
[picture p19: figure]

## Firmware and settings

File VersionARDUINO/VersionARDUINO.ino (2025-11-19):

// =====================================================
// ESTACIÓN METEOROLÓGICA - PROGRAMA PRINCIPAL
// =====================================================
#include "config.h"

// ---------------- LIBRERÍAS ----------------
#include <Wire.h>
#include "lcd.h"
#include "navegacion.h"

// ---------------- MÓDULOS ----------------
#include "bmp280.h"
// #include "ds18b20.h"
#include "csmsv2.h"
#include "bh1750.h"
#include "mq135.h"
#include "gy906.h"
#include "ds3231.h"
#include "microsd.h"
#include "leds_guia.h"

// =====================================================
// SETUP
// =====================================================
void setup()
{
    Serial.begin(9600);
    Wire.begin();

    iniciarLCD();
    iniciarLedsPantalla();

    iniciarRTC();
    iniciarBMP();
    iniciarBH1750();
    iniciarGY906();
    // iniciarDS18B20();
    iniciarCSMSV2();
    iniciarMQ135();
    iniciarNavegacion();
    iniciarSD();
}

// =====================================================
// LOOP PRINCIPAL
// =====================================================
void loop()
{
    // leerNavegacion(); // Deshabilitado - cambio automático de pantallas
    leerRTC();
    leerBMP();
    delay(10); // Pequeño delay para evitar interferencia entre I2C y analógico
    leerBH1750();
    leerGY906();
    // leerDS18B20();
    leerCSMSV2();
    calibrarMQ135();
    leerMQ135();

    // --- Escritura controlada en SD cada 5 segundos ---
    static unsigned long ultimoSD = 0;
    if (millis() - ultimoSD >= 5000)
    {
        escribirSD("registro.txt");
        ultimoSD = millis();
    }

    // --- LED indicador de pantalla ---
    cambiarLedPantalla(pantallaActual);

    // --- Actualizar pantalla cada 500 ms ---
    static unsigned long ultimoLCD = 0;
    if (millis() - ultimoLCD >= 500)
    {
        actualizarLCD();
        ultimoLCD = millis();
    }
}
